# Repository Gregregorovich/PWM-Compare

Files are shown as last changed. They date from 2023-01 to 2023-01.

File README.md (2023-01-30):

# PWM-Compare
Compares two different computer fan PWM duty cycles and outputs the highest duty cycle

N.B. Dependent on the statistics micropython library found at https://github.com/rcolistete/MicroPython_Statistics

The aim of this is to compare fan speeds for case fans as determined by CPU and GPU temperature and still allow for monitoring of each fan via their tach pin (IE not using a PWM splitter).

This would also be ideal for a (especially single-loop) watercooling system with both CPU and GPU in the loop.

This has been designed for a dual core microcontroller like the Raspberry Pi Pico, but with minimal tweaking it could be adjusted to a single core microcontroller.

Designed-for scenario:
* I have 6 fan headers on my motherboard, and 6 on my Corsair Commander Pro.
* I have 6 case fans and a mid-case mounted radiator for my CPU with 4 attached fans.

Corsair iCUE allows me to set a fan curve based on GPU temperature.
My motherboard's BIOS/UEFI allows me to set a fan curve based on CPU temperature.

I have Noctua iPPC 3000 RPM fans, as I wanted black Noctua fans and the Chromax ones hadn't yet been released. I never want to run them at 100%, so if 100% duty cycle is detected it assumes there is no control yet so defaults to 37.5%; enough to have plenty of airflow and also be relatively quiet - when my computer starts up it won't sound like a jet taking off anymore as they default to 100%.

Further info of the reason why I did this can be found at https://forum.level1techs.com/t/gpu-and-cpu-dependent-case-fan-control-with-kvm-using-linux-and-windows-software/191877

Stripboard layout I used:

FanPWM_2 1_Pico

Due to issues with getting a reliable PWM value when the pulse was either high or low for over 50% duty cycle, I experimented with using the ADC (GP26/GP27) as a voltmeter which required using a potential divider to step the voltage down from 5V, but that ended up being completely unreliable, so the risistors are ignorable. Update: a capacitor would probably smooth the voltage and make it more reliable, but it works as it is so I'm not going to further experiment at least for now. Same goes for the wire soldered between the PWM output and GP12 as I thought I needed to wait for the PWM duty cycle to finish before updating the duty cycle as iCUE scales the RPM monitor graph to the lowest and highest in the stated timeframe, rather than setting the bottom of the graph to 0, so I didn't initially realise that the spiky graph was a fluctuation of a couple RPM rather than what it looked like, which was a couple hundred.

PXL_20230121_153830263 MP

PXL_20230121_153856360 MP

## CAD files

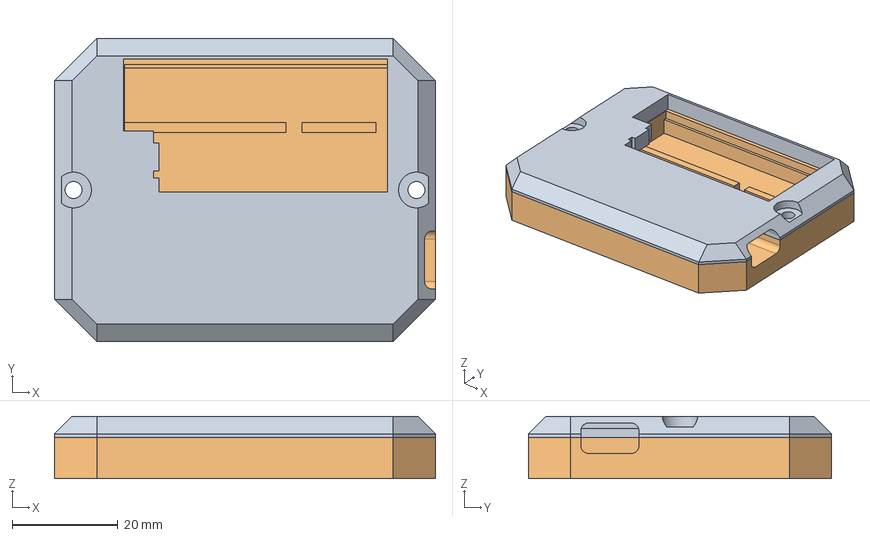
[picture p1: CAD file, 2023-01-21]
Pico PWM Hub v4.step
71.9 x 57.3 x 11.8 mm

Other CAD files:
Pico PWM Hub v4.f3d

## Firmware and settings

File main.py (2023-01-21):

from machine import *
import time, _thread, statistics

#Define CPU PWM Pin
cpu_pin = Pin(0)
#Define GPU PWM Pin
gpu_pin = Pin(4)
#Define PWM Output
fan = machine.PWM(machine.Pin(8))
#Wait for PWM Output to finish before changing duty cycle
#output_pin = Pin(12)

#Computer fan PWM frequency = 25kHz = 25000Hz
fan.freq(25000)

#Define Maximum PWM pulse length in microseconds (1/25k)
#pwm_pulse = 100000
pwm_pulse = 40

n = 40

#Define global CPU arguments; set to 0
#CPU PWM time in microseconds
cpu = 0
cpu_off = 0
cpu_output = 0
cpu_av=[0] * n
cpu_av_off=[0] * n
#Time at start of CPU PWM pulse in microseconds
cpu_t_off = 0
#Time at end of CPU PWM pulse in microseconds
cpu_t = 0

#Define global GPU arguments; set to 0
#GPU PWM time in microseconds
gpu = 0
gpu_off = 0
gpu_output = 0
gpu_av=[0] * n
gpu_av_off=[0] * n
#Time at start of GPU PWM pulse in microseconds
gpu_t_off = 0
#Time at end of GPU PWM pulse in microseconds
gpu_t = 0

def CPU_PWM_TIMER(cpu_pin,pwm_pulse):
    global cpu
    global cpu_off
    global cpu_av
    global cpu_av_off
    global cpu_output
    #global cpu_t_off
    #global cpu_t
    global wait_for_CPU
    i=0
    #Wait for CPU PWM pulse to be off
    machine.time_pulse_us(cpu_pin, 0, pwm_pulse)
    machine.time_pulse_us(cpu_pin, 1, pwm_pulse)
    
    #Measure Time PWM Pulse is on and take a median
    for x in cpu_av:
        #Record time at start of PWM pulse
        #cpu_t_off = time.ticks_us()
        
        #Time CPU PWM pulse on (else could start part-way through pulse)
        cpu_av[i] = machine.time_pulse_us(cpu_pin, 1, pwm_pulse)
        
        #Record time at end of PWM pulse
        #cpu_t = time.ticks_us()
        i += 1
    
    cpu = (statistics.median(cpu_av))
    
    i=0
    #Measure Time PWM Pulse is off and take a median
    for x in cpu_av_off:
        cpu_av_off[i] = machine.time_pulse_us(cpu_pin, 0, pwm_pulse)
        i += 1
    
    cpu_off = (statistics.median(cpu_av_off))
    
    #Anything over 50% either on or off doesn't seem to measure reliably;
    #Take the smallest value, and if it's the time the pulse is off, invert it,
    # unless it is always on, which would give "off" a value of "-2", whilst
    # "on" would give "-1"
    if cpu_off<cpu:
        if cpu_off > 0:
            cpu_output = 40-cpu_off
        else:
            cpu_output = cpu
    else:
        cpu_output = cpu
    
    #Set CPU PWM analysis as done
    wait_for_CPU = 0
    #Wait for GPU PWM analysis
    while wait_for_GPU == 1:
        time.sleep_us(1)
    
    return

def GPU_PWM_TIMER(gpu_pin,pwm_pulse):
    global gpu
    global gpu_off
    global gpu_av
    global gpu_av_off
    global gpu_output
    #global gpu_t_off
    #global gpu_t
    global wait_for_GPU
    i=0
    #Wait for GPU PWM pulse to be off
    machine.time_pulse_us(gpu_pin, 0, pwm_pulse)
    machine.time_pulse_us(gpu_pin, 1, pwm_pulse)
    
    for x in gpu_av:
        #Record time at start of PWM pulse
        #gpu_t_off = time.ticks_us()
        
        #Time GPU PWM pulse on
        gpu_av[i] = machine.time_pulse_us(gpu_pin, 1, pwm_pulse)
        
        #Record time at end of PWM pulse
        #gpu_t = time.ticks_us()
        i += 1
    
    gpu = (statistics.median(gpu_av))
    
    i=0
    #Measure Time PWM Pulse is on and take a median
    for x in gpu_av_off:
        gpu_av_off[i] = machine.time_pulse_us(gpu_pin, 0, pwm_pulse)
        i += 1
    
    gpu_off = (statistics.median(gpu_av_off))
    
    if gpu_off<gpu:
        if gpu_off > 0:
            gpu_output = 40-gpu_off
        else:
            gpu_output = gpu
    else:
        gpu_output = gpu
    
    #Set GPU PWM analysis as done
    wait_for_GPU=0
    #Wait for CPU PWM analysis
    while wait_for_CPU == 1:
        time.sleep_us(1)
    
    return

#Loop forever
while True:
#Loop once for testing
#i=0
#while i<1:

    #Wait for CPU PWM pulse to finish: Reset variables
    wait_for_CPU = 1
    wait_for_GPU = 1
    
    #Assign core1 to PWM analysis
    #_thread.start_new_thread(CPU_PWM_TIMER, (cpu_pin,pwm_pulse))
    _thread.start_new_thread(GPU_PWM_TIMER, (gpu_pin,pwm_pulse))
    
    #Use core0 for PWM analysis
    CPU_PWM_TIMER(cpu_pin,pwm_pulse)
    #GPU_PWM_TIMER(gpu_pin,pwm_pulse)
    
    #Debug
    #print("Time for PWM pulse","PWM Duty","Wait for code to finish?")
    #print(cpu_t-cpu_t_off,cpu,wait_for_CPU)
    #print(gpu_t-gpu_t_off,gpu,wait_for_CPU)
    #print("Difference between end of CPU and end of GPU code in us")
    #print(cpu_t_off-gpu_t_off,cpu_t-gpu_t)
    
    #print(cpu_av)
    #print(cpu_av_off)
    #print(cpu,cpu_off,cpu_output)
    
    #print(gpu_av)
    #print(gpu_av_off)
    #print(gpu,gpu_off,gpu_output)
    
    #print("thread exit")
    #_thread.exit()
    #return
    
    if cpu_output > gpu_output:
        fanDuty = cpu_output *1000
        #print("CPU")
    else:
        fanDuty = gpu_output *1000
        #print("GPU")
    
    if fanDuty == -2000:
        #Set PWM Duty to 10% if both CPU and GPU fan are off
        fanDuty = 4000
        #print("10%")
    elif fanDuty == -1000:
        #Set PWM Duty to 37.5% if both CPU and GPU fan are at 100%
        fanDuty = 15000
        #print("100%")
    
    #Wait for PWM duty cycle to finish pulse on and off to prevent spiky output
    #machine.time_pulse_us(output_pin, 0, pwm_pulse)
    #Set PWM Duty to the higher of CPU / GPU
    fan.duty_ns(int(fanDuty))
    #print(fanDuty,fanDuty/400)
    
    #i+=1

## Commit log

2023-01-21 Fixed >50% duty cycle being unreliable; will now output up to ~97% (as 100% is manually mapped to 37.5%)
    [main.py]
2023-01-21 3D Printable Case for Raspberry Pi Pico and stripboard
    [Pico PWM Hub v4.f3d, Pico PWM Hub v4.step]
